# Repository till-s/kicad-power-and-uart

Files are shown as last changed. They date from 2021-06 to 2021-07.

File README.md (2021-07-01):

# USBC Power and UART Module

A small module (~40mmx25mm) powered by USB-C which provides
a 3.3V/3A power-converter and a UART.

# Features
 - detects available power of upstream port
 - jumper to select 1.5A or 3A capability (the power-supply
   remains OFF if the upstream port does not provide enough
   current).
 - LED indicates insufficient upstream power.
 - FT232 UART
 - (Optional) additional legacy mini-USB connector can
   be jumpered to provide USB data. The idea is that you
   can use a (permanent) USB-C power supply (wall-wart) and 
   use the legacy connector, e.g., for a temporary debugging
   session.
     - power always from USB-C
     - data either from USB-C or legacy as selected by jumper

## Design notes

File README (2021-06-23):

Fork of power-test-1 with reference numbers starting at 1000.
Helps importing into other projects.

Note: re-annotating schematic from kicad and re-importing into pcbnew
works!!! So it is easy to change the base to something else...

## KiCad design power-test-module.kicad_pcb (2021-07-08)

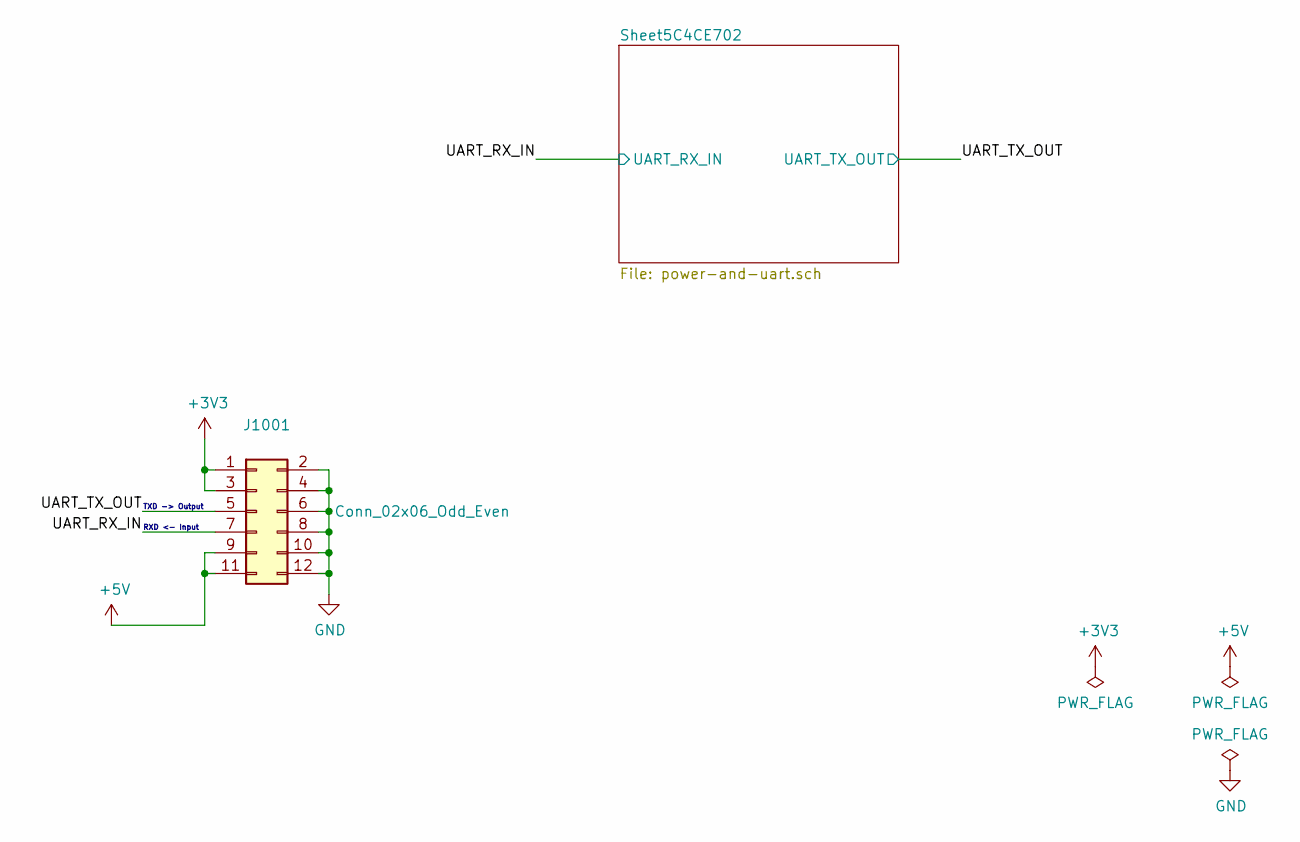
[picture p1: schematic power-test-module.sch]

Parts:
J1001: Conn_02x06_Odd_Even; PinHeader_2x06_P2.54mm_Vertical

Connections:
+3V3_PWR_OUT: J1001.1, J1001.3; also elsewhere on the board
+5V_PWR_OUT: J1001.9, J1001.11; also elsewhere on the board
/UART_RX_IN: J1001.7; also elsewhere on the board
/UART_TX_OUT: J1001.5; also elsewhere on the board
GND: J1001.2, J1001.4, J1001.6, J1001.8, J1001.10, J1001.12; also elsewhere on the board

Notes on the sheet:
TXD -> Output
RXD <- Input

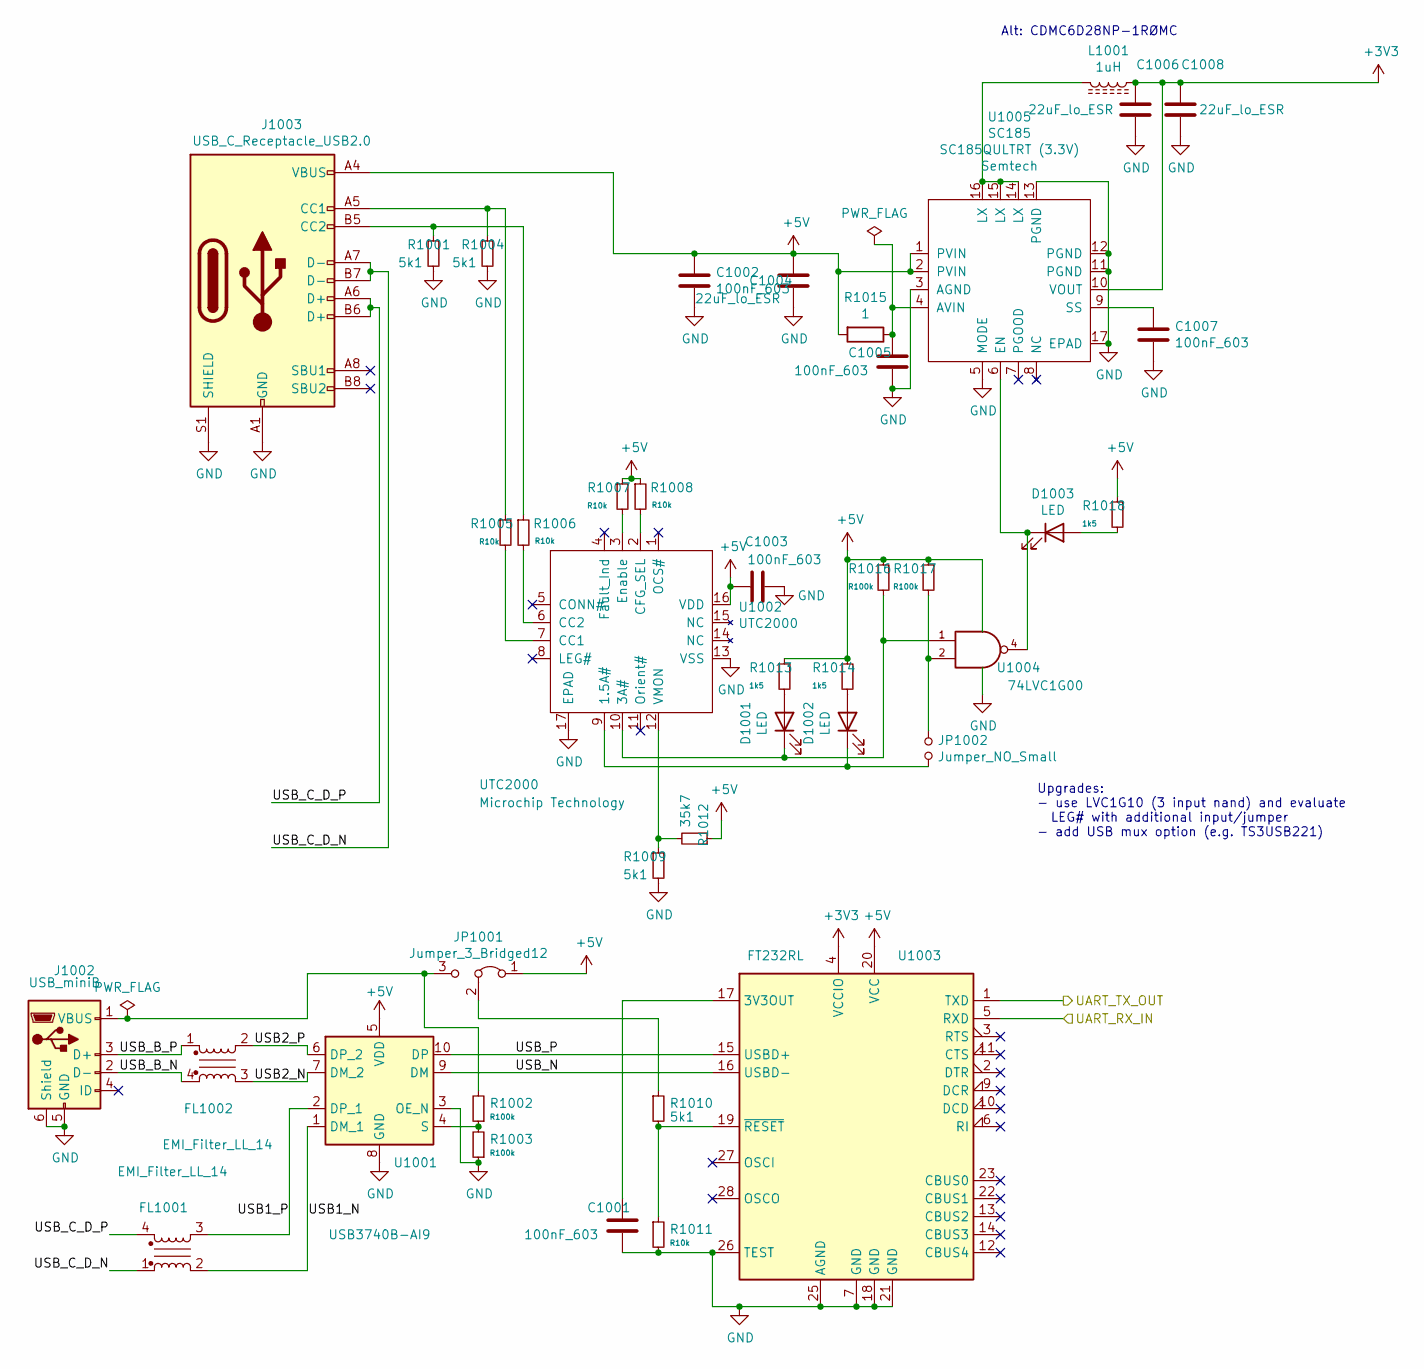
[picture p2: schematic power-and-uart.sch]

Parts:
C1001, C1002, C1003, C1005, C1007: 100nF_603; C_0603_1608Metric; Part GCJ188R71E104KA12D
C1004, C1006, C1008: 22uF_lo_ESR; C_1812_4532Metric; Part C4532X7R1E226M250KC
D1001, D1002: LED; LED_0603_1608Metric; Part 150060GS75000
D1003: LED; LED_0603_1608Metric; Part 150060RS75000
FL1001, FL1002: EMI_Filter_LL_14; WE_CNSW; Part 744231371
J1002: USB_miniB; USB_Micro-B_Molex_47346-0001
J1003: USB_C_Receptacle_USB2.0; USB_C_Receptacle_GCT_USB4085_smaller_holes
JP1001: Jumper_3_Bridged12; PinHeader_1x03_P2.54mm_Vertical
JP1002: Jumper_NO_Small; PinHeader_1x02_P2.54mm_Vertical
L1001: 1uH; L_CDMC6D28; Part CDMC6D28NP-1R0MC
R1001, R1004, R1009, R1010: 5k1; R_0603_1608Metric
R1002, R1003, R1016, R1017: R100k; R_0603_1608Metric
R1005, R1006, R1007, R1008, R1011: R10k; R_0603_1608Metric
R1012: 35k7; R_0603_1608Metric
R1013, R1014, R1018: 1k5; R_0603_1608Metric
R1015: 1; R_0603_1608Metric
U1001: USB3740B-AI9; UQFN-10_1.6x2.1mm_P0.5mm
U1002: UTC2000; QFN-16-1EP_3x3mm_P0.5mm_EP1.8x1.8mm; Part UTC2000
U1003: FT232RL; SSOP-28_5.3x10.2mm_P0.65mm
U1004: 74LVC1G00; SOT-23-5
U1005: SC185; QFN-16-1EP_3x3mm_P0.5mm_EP1.8x1.8mm; Part SC185QULTRT (3.3V)

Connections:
+3V3_PWR_OUT: C1006.1, C1008.1, L1001.1, U1003.4 (VCCIO), U1005.10 (VOUT); also elsewhere on the board
+5V_PWR_OUT: C1002.1, C1003.2, C1004.1, J1003.A4 (VBUS), J1003.A9 (VBUS), J1003.B4 (VBUS), J1003.B9 (VBUS), JP1001.1 (A), R1007.1, R1008.1, R1012.1, R1013.1, R1014.1, R1015.2, R1016.1, R1017.1, R1018.1, U1001.5 (VDD), U1002.16 (VDD), U1003.20 (VCC), U1004.5 (VCC), U1005.1 (PVIN), U1005.2 (PVIN); also elsewhere on the board
/Sheet5C4CE702/USB1_N: FL1001.2, U1001.1 (DM_1)
/Sheet5C4CE702/USB1_P: FL1001.3, U1001.2 (DP_1)
/Sheet5C4CE702/USB2_N: FL1002.3, U1001.7 (DM_2)
/Sheet5C4CE702/USB2_P: FL1002.2, U1001.6 (DP_2)
/Sheet5C4CE702/USB_B_N: FL1002.4, J1002.2 (D-)
/Sheet5C4CE702/USB_B_P: FL1002.1, J1002.3 (D+)
/Sheet5C4CE702/USB_C_D_N: FL1001.1, J1003.A7 (D-), J1003.B7 (D-)
/Sheet5C4CE702/USB_C_D_P: FL1001.4, J1003.A6 (D+), J1003.B6 (D+)
/Sheet5C4CE702/USB_N: U1001.9 (DM), U1003.16 (USBD-)
/Sheet5C4CE702/USB_P: U1001.10 (DP), U1003.15 (USBD+)
/UART_RX_IN: U1003.5 (RXD); also elsewhere on the board
/UART_TX_OUT: U1003.1 (TXD); also elsewhere on the board
GND: C1001.2, C1002.2, C1003.1, C1004.2, C1005.2, C1006.2, C1007.2, C1008.2, J1002.5 (GND), J1002.6 (Shield), J1003.A1 (GND), J1003.A12 (GND), J1003.B1 (GND), J1003.B12 (GND), J1003.S1 (SHIELD), R1001.2, R1003.1, R1004.2, R1009.2, R1011.2, U1001.3 (OE_N), U1001.8 (GND), U1002.13 (VSS), U1002.17 (EPAD), U1003.7 (GND), U1003.18 (GND), U1003.21 (GND), U1003.25 (AGND), U1003.26 (TEST), U1004.3 (GND), U1005.3 (AGND), U1005.5 (MODE), U1005.11 (PGND), U1005.12 (PGND), U1005.13 (PGND), U1005.17 (EPAD); also elsewhere on the board
unnamed: C1001.1, U1003.17 (3V3OUT)
unnamed: C1005.1, R1015.1, U1005.4 (AVIN)
unnamed: C1007.1, U1005.9 (SS)
unnamed: D1001.1 (K), R1016.2, U1002.10 (3A#), U1004.1
unnamed: D1001.2 (A), R1013.2
unnamed: D1002.1 (K), JP1002.2, U1002.9 (1.5A#)
unnamed: D1002.2 (A), R1014.2
unnamed: D1003.1 (K), U1004.4, U1005.6 (EN)
unnamed: D1003.2 (A), R1018.2
unnamed: J1002.1 (VBUS), JP1001.3 (B), R1002.2
unnamed: J1003.A5 (CC1), R1004.1, R1005.1
unnamed: J1003.B5 (CC2), R1001.1, R1006.1
unnamed: JP1001.2 (C), R1010.1
unnamed: JP1002.1, R1017.2, U1004.2
unnamed: L1001.2, U1005.14 (LX), U1005.15 (LX), U1005.16 (LX)
unnamed: R1002.1, R1003.2, U1001.4 (S)
unnamed: R1005.2, U1002.7 (CC1)
unnamed: R1006.2, U1002.6 (CC2)
unnamed: R1007.2, U1002.3 (Enable)
unnamed: R1008.2, U1002.2 (CFG_SEL)
unnamed: R1009.1, R1012.2, U1002.12 (VMON)
unnamed: R1010.2, R1011.1, U1003.19 (~RESET~)

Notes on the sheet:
Alt: CDMC6D28NP-1RØMC
Upgrades: - use LVC1G10 (3 input nand) and evaluate LEG# with additional input/jumper - add USB mux option (e.g. TS3USB221)

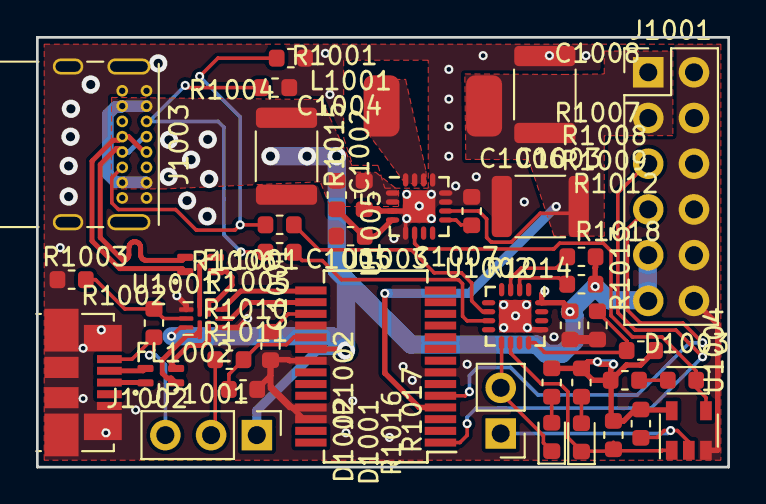
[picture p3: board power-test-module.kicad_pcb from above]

Board: 2 copper layers, 38.4 x 23.9 mm, 42 parts (0 on the bottom side), 37 nets.

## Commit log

2021-06-23 git import of power-test-1
    [power-and-uart.sch, power-test-1.kicad_pcb, power-test-1.sch]
2021-06-23 renaming power-test-1 -> power-test-module (step 1, renaming files)
    [power-test-module.kicad_pcb, power-test-module.sch]
2021-06-23 renamed power-test-1 -> power-test-module in resp. files
    [power-and-uart.sch, power-test-module.sch]
2021-06-23 updated library symbols (usb-c, usb-otg, ft232)
    [power-and-uart.sch, power-test-module.sch]
2021-06-23 replaced VIN_3V3 with original symbol from trigbox.lib
    [power-and-uart.sch, power-test-module.sch]
2021-06-23 Revert "replaced VIN_3V3 with original symbol from trigbox.lib"
    This reverts commit 9420d5290e32625fca25a5553c309d02b920cb52.
    [power-and-uart.sch, power-test-module.sch]
2021-06-23 replaced VIN3V3 with original from trigbox.lib
    [power-and-uart.sch, power-test-module.sch]
2021-06-23 replaced resistor symbols with originals from trigbox.lib
    [power-and-uart.sch, power-test-module.kicad_pcb]
2021-06-23 replaced all rescued symbols by originals from trigbox.lib; removed rescue.lib
    [power-and-uart.sch, power-test-module.kicad_pcb]
2021-06-23 fixed design-rule issues
    - removed stray via
    - replaced 2 single-row headers by a 2x6 (vertical) header to
    avoid court-yard overlaps.
    [power-test-module.kicad_pcb, power-test-module.sch]
2021-06-23 re-annotated with base number 1000
    [power-and-uart.sch, power-test-module.kicad_pcb, power-test-module.sch]
2021-06-23 use hierarchical labels from power-and-uart sheet
    [power-and-uart.sch, power-test-module.kicad_pcb, power-test-module.sch]
2021-06-23 use QFN-16 footprint from proj-library
    [power-and-uart.sch, power-test-module.kicad_pcb]
2021-06-28 swapped USBC connector; jlcpcb hole distance.
    - use usbc-usb2.0 variant with more power pins
    - enforce .5mm hole spacing (jlcpcb)
    [power-and-uart.sch, power-test-module.kicad_pcb]
2021-06-28 use special +5/+3V3 labels with more specific net names
    This allows easier integration since these are global labels
    and using more specific names helps avoiding clashes.
    The labels are stored in the 'rescue' library.
    Strangely: the same trick did not work for GND. Kicad always
    insists the net name remains 'GND' (it does work, however if
    a new schematic is created - then the different net name for
    GND 'sticks').
    [power-and-uart.sch, power-test-module.kicad_pcb, power-test-module.sch]
2021-06-28 removed global labels for UART-TX/RX
    There referred to MIO pins on the CPU board which don't really
    belong here; also: avoid global labels for a module.
    [power-test-module.kicad_pcb, power-test-module.sch]
2021-07-07 added part numbers for EMI filter + LEDs;
    Also changed reset pullup from 4k7 to 5k1 (for sake of fewer different values)
    [power-and-uart.sch, power-test-module.kicad_pcb]
2021-07-07 added/updated part number of inductor
    [power-and-uart.sch, power-test-module.kicad_pcb]
2021-07-08 PCB: fixed USB4085 footprint; has wrong slits
    [power-test-module.kicad_pcb]
